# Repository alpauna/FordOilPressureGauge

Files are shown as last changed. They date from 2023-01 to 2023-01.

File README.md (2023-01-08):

# FordOilPressureGauge
Add actual oil pressure to Ford and allows for dash light to still work via ATTiny uCPU

## Hardware
Uses a board that I developed and all is in schematics folder.

## Software
Arduino based ATTiny85 for original revision.
New revision is ATTiny1624 and it will add buttons so that some items can be adjusted

## Blog
Check out the progress of this in my [alshowto.com](https://alshowto.com) page. Also, you can check out the tag related to the truck that 
inspired this project: [99 f150](https://alshowto.com/tag/99-f150/).

Finally, if just insterested in this project check out the blog on it. [Add an Actual Oil Pressure Gauge](https://alshowto.com/99-f150-add-an-actual-oil-pressure-gauge/)

## Latest development

## Testing
Testing the drive capability of the n-mosfet. However for the truck it is simply switching the dash oil circuit to ground so it should be very low current.

## Dash circuit


As seen above, I think this circuit is grounded out to turn the oil light on so the code will drive pin 17 high to turn on the MOSFET and this will then send that dash circuit Pin 6 on I/O connector to ground. The code is set to do this if the pressure drops below 10 PSI. I think the original circuit did this at 7 psi. currentOilPressureDriverSch

I will provide more specifics once I fully test this on my trucks. This may be exactly backward and it should be grounded when the light is off and basically open to have the light on. Running on my truck will verify this fact. That will happen sometime next month with my prototype board running the ATTiny85.



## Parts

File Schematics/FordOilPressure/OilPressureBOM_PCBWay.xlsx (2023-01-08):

 |  |  | xxxx xxxx xxxxx xxPCS BOM (Sample Bill of Materials)
Item # | *Designator | *Qty | Manufacturer | *Mfg Part # | Description / Value | *Package/Footprint | Type | Your Instructions / Notes
1 | C1,C3 | 2 | Murata Electronics | GRM188R6YA106MA73D | 35V 10uF ±20% 0603 Multilayer Ceramic Capacitors | 0603 | SMD
2 | C2 | 1 | Knowles | 0603Y0250104KET | 25V 100nF ±10% 0603 Multilayer Ceramic Capacitors | 0603 | SMD
3 | D1 | 1 | Shikues | MBR130 | 30V 470mV@1A 1A SOD-123 Schottky Barrier Diodes | SOD-123 | SMD
4 | D2 | 1 | Diodes Inc | DDZ5V1B-7 | 5uA@1.5V 17Ω Single 4.94V~5.2V 470mW Zener Diodes | SOD-123 | SMD
5 | J1 | 1 | TE Connectivity | 5-146258-3 | Connector_PinHeader_2.54mm:PinHeader_2x03_P2.54mm_Vertical | 2.54 Pin Header | thru-hole
6 | J2 | 1 | TE Connectivity | 5-146258-3 | Connector_PinHeader_2.54mm:PinHeader_2x03_P2.54mm_Vertical | 2.54 Pin Header | thru-hole
7 | J3 | 1 | Amphenol ICC | 68001-204HLF | Connector_PinHeader_2.54mm:PinHeader_1x04_P2.54mm_Vertical | 2.54 Pin Header | thru-hole
8 | Q1 | 1 | Nexperia | PHB21N06LT,118 | MOSFET 55v 19a 2v GS | SOT404 | SMD
9 | R1 | 1 | Vishay Intertech | MCT06030C1005FP500 | 100mW 10MΩ 0603 Chip Resistor | 0603 | SMD
10 | R2,R3 | 2 | BOURNS | CR0603AFX-1001ELF | 100mW 1KΩ 0603 Chip Resistor | 0603 | DNS
11 | U1 | 1 | Microchip Tech | ATTINY85-20SF | uConn 4K@x16bit -40℃~+85℃ 2.7V~5.5V AVR 1@x4ch/10bit Yes 20MHz 6 512Byte | SOIC-8 | SMD
12 | U2 | 1 | HGSEMI | LM1085S-5.0/TR | 3AFixed 5V~5V Positive 1 15V TO-263-3 Linear Voltage Regulators | TO-263-3 | SMD
Need a quick and accurante quote? Need an efficient production? Please read SMT Ordering Necessary Files & Info in 1 minute. Thank you very much! (https://www.pcbway.com/smt_ordering_guide.html)
Click for Instructions on How to Create a BOM (https://www.pcbway.com/blog/PCB_Assembly/How_to_Build_a_BOM__Bill_Of_Materials_.html)

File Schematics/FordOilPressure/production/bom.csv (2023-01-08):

Designator | Footprint | Quantity | Value | LCSC Part #
C1 C3 | C_0603_1608Metric_Pad1.08x0.95mm_HandSolder | 2 | 10uF | C194427
C2 | C_0603_1608Metric_Pad1.08x0.95mm_HandSolder | 1 | .1uF | C2180759
D1 | D_SOD-123F | 1 | 1 amp | C126484
D2 | D_SOD-123 | 1 | 5.1 v | C151576
J1 | PinHeader_2x03_P2.54mm_Vertical | 1 | I/O Connector | C3348967
J2 | PinHeader_2x03_P2.54mm_Vertical | 1 | ISP Prog | C3348967
J3 | PinHeader_1x04_P2.54mm_Vertical | 1 | LCD Conn | C3338160
Q1 | TO-263-2 | 1 | PHB21N06LT,118 | C552623
R1 | R_0603_1608Metric_Pad0.98x0.95mm_HandSolder | 1 | 10M | C2653999
R2 R3 | R_0603_1608Metric_Pad0.98x0.95mm_HandSolder | 2 | 1k | C1870265
U1 | SOIC-8W_5.3x5.3mm_P1.27mm | 1 | ATtiny85-20S | C615549
U2 | TO-263-3_TabPin2 | 1 | LM1085-5.0 | C434505

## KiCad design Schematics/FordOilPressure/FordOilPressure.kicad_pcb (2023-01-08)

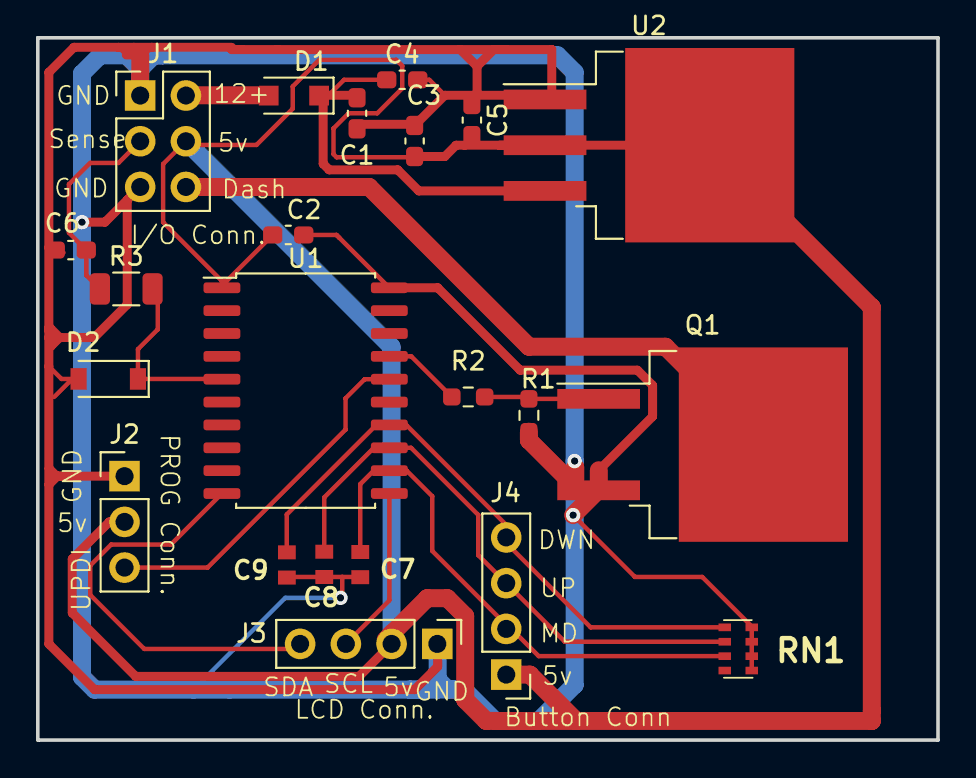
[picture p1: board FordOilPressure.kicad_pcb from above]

Board: 2 copper layers, 50.0 x 39.0 mm, 22 parts (0 on the bottom side), 15 nets.

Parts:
C1, C5: 10uF; C_0603_1608Metric_Pad1.08x0.95mm_HandSolder
C2, C4: .1uF; C_0603_1608Metric_Pad1.08x0.95mm_HandSolder
C3, C6: .33uF; C_0603_1608Metric_Pad1.08x0.95mm_HandSolder
C7, C8, C9: 0603YC105KAT2A; CAPC1608X94N
D1: 1 amp; D_SOD-123F
D2: 5.1 v; D_SOD-123
J1: I/O Connector; PinHeader_2x03_P2.54mm_Vertical
J2: UPDI; PinHeader_1x03_P2.54mm_Vertical
J3: LCD Conn; PinHeader_1x04_P2.54mm_Vertical
J4: Btn Connect; PinHeader_1x04_P2.54mm_Vertical
Q1: PHB21N06LT,118; TO-263-2
R1: 10M; R_0603_1608Metric_Pad0.98x0.95mm_HandSolder
R2: 1k; R_0603_1608Metric_Pad0.98x0.95mm_HandSolder
R3: 1k; R_1206_3216Metric
RN1: EXBV8V683JV; EXBV8V101JV
U1: ATtiny1616-S; SOIC-20W_7.5x12.8mm_P1.27mm
U2: LM1085-5.0; TO-263-3_TabPin2

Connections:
GND: C1.1, C2.2, C3.2, C4.2, C5.1, C6.1, C7.1, C8.1, C9.1, D2.2 (A), J1.1, J1.5, J2.1, J3.1, Q1.3 (S), R1.2, RN1.1, RN1.2, RN1.3, RN1.4, U1.20 (GND), U2.1 (GND)
unnamed: C2.1, C3.1, C5.2, J1.4, J2.2, J3.2, J4.1, U1.1 (VCC), U2.2 (VO)
unnamed: D1.2 (A), J1.2
unnamed: D2.1 (K), R3.2, U1.5 (PA7)
unnamed: C6.2, J1.3, R3.1
unnamed: J1.6, Q1.2 (D)
unnamed: J2.3, U1.16 (~RESET/PA0)
unnamed: J3.3, U1.11 (PB0)
unnamed: J3.4, U1.10 (PB1)
unnamed: Q1.1 (G), R1.1, R2.2
unnamed: R2.1, U1.17 (PA1)
unnamed: C7.2, J4.2, RN1.7, U1.12 (PC0)
unnamed: C8.2, J4.3, RN1.6, U1.13 (PC1)
unnamed: C9.2, J4.4, RN1.5, U1.14 (PC2)
unnamed: C1.2, C4.1, D1.1 (K), U2.3 (VI)

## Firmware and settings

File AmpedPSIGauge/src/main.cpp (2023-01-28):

#include <Arduino.h>
#include <EEPROM.h>
#include <TinyWireM.h> 
#define TINY4KOLED_QUICK_BEGIN
#include <Tiny4kOLED.h>
#include <Button.h>
//#include "RunningAverage.h"

//RunningAverage myRA(5);

#define PRES_ADC A2
#define BUTTON_PIN PB3
#define DAC_MIN_REF 90
#define DAC_MAX_REF 860
#define MIN_DAC_INIT_CHECK_MS 30000
#define OUT_DASH PB1
#define DAC_CONV 5.0/1023.0

unsigned short dacMin = DAC_MIN_REF;
unsigned short dacMax = DAC_MAX_REF;
unsigned short rawDac = 0;
bool last_button_state = false;
bool dacAdjusted = false;
bool mainMenuEnabled = false;
bool longPress = false;
unsigned long uTickTimeGetPress, uTickTimeUpdateLCD, uTickMainMenu, uTickCheck, uTickButtons,uTickButtonPressed;

float average_pressure = 0.0F;


void updatePressureInit(unsigned short dac);
void getPressureADC(void);
void PrintText(const __FlashStringHelper * text);

Button button(BUTTON_PIN);

float getScaledValue(unsigned short value)
{
  
  return (float)map(value, dacMin, dacMax, 0, 1000) / 10.0;
}
long getScaledScreen(unsigned short value)
{
  
  return map(value, 0, 1000, 0, 220) / 10;
}

void SetDacMin()
{
  EEPROM.get<unsigned short>(0, dacMin);
  EEPROM.get<unsigned short>(sizeof(unsigned short), dacMax);
   if(dacMin > DAC_MIN_REF * 2){
    dacMax = DAC_MAX_REF;
    dacAdjusted = false;   
    dacMin = DAC_MIN_REF;
  }else
  {
    dacAdjusted = true; 
     
  }
  unsigned long curMillis = millis();
  unsigned long curMillis2 = curMillis ;
  if(!dacAdjusted){
    
    while(millis() - curMillis <  MIN_DAC_INIT_CHECK_MS){
      delay(200);
      unsigned short dac = analogRead(PRES_ADC);
      if(dac < dacMin && dac > 0)
      {
        dacMin--;
      }
      if(dac > dacMin && dac < 200){
        dacMin++;
      }
      
      if(millis() - curMillis2 >= 1000){
        updatePressureInit(dacMin);
        curMillis2 = millis();
      } 
    }
    dacMax -= DAC_MIN_REF - dacMin;
    dacAdjusted = true;
    EEPROM.put<unsigned short>(0, dacMin);
    EEPROM.put<unsigned short>(sizeof(unsigned short), dacMax);
  }
}

void getPressureADC() {
  rawDac = analogRead(PRES_ADC); 
  //myRA.addValue(rawDac);
  float val = 0;
  //average_pressure = getScaledValue(myRA.getAverage()); 
  if(rawDac >= dacMin){
    val = getScaledValue(rawDac); 
  }
  if(average_pressure > 0.0F){
    average_pressure = (average_pressure + val) / 2; 
  }
  else{
    average_pressure = val; 
  }
  if(average_pressure < 10.0F)
  {
      digitalWrite(1, HIGH);
  }
  else
  {
      digitalWrite(1, LOW);
  }
}

void updatePressureInit(unsigned short dac)
{
  oled.clear();
  oled.setFont(FONT6X8);
  oled.println(F("Zeroing..."));
  oled.print(F("Dac:"));
  //float val = DAC_CONV * (float)dac;
  oled.println(dac);
  oled.switchFrame();
}

void updatePressure()
{
  oled.clear();
  oled.setFont(FONT6X8);
  oled.println(F("Oil Pressure: "));
  oled.setFont(FONT8X16);
  oled.setCursor(40,1);
  //oled.setFontX2(FONT6X8);
  oled.println(average_pressure);
  oled.setFont(FONT6X8);
  //oled.println(getScaledScreen(average_pressure));
  oled.setCursor(0,3);
  for(int i = 0; i < getScaledScreen(average_pressure*10); i++ ){
    oled.print(F("="));
  }
  oled.switchFrame();
}
void EditModeTick();

void showMenu()
{
  PrintText(F("Reset? Press and Hold."));
}

void lpStart(){
  if(!mainMenuEnabled){
    mainMenuEnabled = true;
    uTickMainMenu = millis();
      showMenu();
  }else{
    EEPROM.put<unsigned short>(0, 0xFFFF);
    EEPROM.put<unsigned short>(sizeof(unsigned short), 0xFFFF);
    dacMin = DAC_MIN_REF;
    dacMax = DAC_MAX_REF;
    SetDacMin(); 
  }  
}
void EditModeTick()
{
  mainMenuEnabled = false;
}

void PrintText(const __FlashStringHelper * text){
  oled.clear();
  oled.setFont(FONT8X16);
  oled.println(text);
  oled.switchFrame();
}

//------------------------------------------------------------------------------
void setup() {
  
  pinMode(BUTTON_PIN, INPUT_PULLUP);
  pinMode(OUT_DASH, OUTPUT);
  pinMode(PRES_ADC, INPUT);
  digitalWrite(OUT_DASH, HIGH);

  oled.begin(0,0);
  oled.enableChargePump();
  oled.setRotation(1);
  oled.switchRenderFrame();
  oled.enableZoomIn();
  PrintText(F("AMPED!!!"));
  oled.on();
  delay(2000);
  SetDacMin();
  digitalWrite(OUT_DASH, LOW);
  getPressureADC();
  updatePressure();

  button.begin();
  
}

//------------------------------------------------------------------------------
void loop() {
  uTickCheck = millis();
  if(uTickMainMenu > uTickCheck){
    // This happens when millis runs over and starts over so start all of the ticks over.
    unsigned long change = uTickMainMenu - uTickCheck;
    uTickMainMenu = change;
    uTickTimeGetPress = change;
    uTickTimeUpdateLCD = change;
  }

  if(millis() - uTickTimeGetPress >= 200 )
  {
    getPressureADC();
    uTickTimeGetPress = millis();
  }
  if(millis() - uTickTimeUpdateLCD >= 500 && !mainMenuEnabled)
  {
    updatePressure();
    uTickTimeUpdateLCD = millis();
  }
  if(mainMenuEnabled && millis() - uTickMainMenu >= 30000){
    EditModeTick();
    uTickMainMenu = millis();
  }
  if(button.pressed() && !last_button_state){
    last_button_state = true;
    uTickButtonPressed = millis();
  }
  if(last_button_state &&  millis() - uTickButtonPressed >= 5000){
    lpStart(); 
    last_button_state = false;  
    uTickButtonPressed = 0; 
  }
  if(button.released()){
    last_button_state = false;  
    uTickButtonPressed = 0;
  }
}

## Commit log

2022-12-31 Initial Checkin
    Initial check in of basic working oil pressure sensor .
    [FordOilPressure.csv, FordOilPressure.kicad_pcb, FordOilPressure.kicad_sch]
2023-01-08 updated code that better zeros the pressure gauge.
    This latest code is just before I started to develop for the ATTiny 1624 to replace the ATTiny85 uCPU.
    [main.cpp]
2023-01-08 This is the latest with ATTiny1626
    [FordOilPressure-B_Cu.gbr, FordOilPressure-B_Mask.gbr, FordOilPressure-B_Paste.gbr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]
2023-01-28 Progression On ATTyiny1626
    [freerouting.dsn]
